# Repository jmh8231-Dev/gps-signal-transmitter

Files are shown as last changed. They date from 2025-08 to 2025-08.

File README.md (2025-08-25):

# GPS 데이터 송신기 (STM32F103 + ATmega328P)

두 개의 2.4 GHz RF 모듈(nRF24L01+ PA+LNA)과 GNSS, RTC, 환경 센서, 20×4 문자 LCD를 통합한 **원격 GPS 데이터 송신기**이다. 
보드는 **STM32F103C8T6**를 메인 MCU로, **ATmega328P**(Arduino 호환)를 서브 MCU로 사용한다. 서브 MCU는 센서 보조 처리 및
메인 MCU 상태 감시/리셋 보조를 담당한다. 펌웨어는 UBX 프로토콜로 GPS 시간을 수신하여 RTC(DS3231)를 보정하고,
RF/USB/UART로 상태를 송신한다.

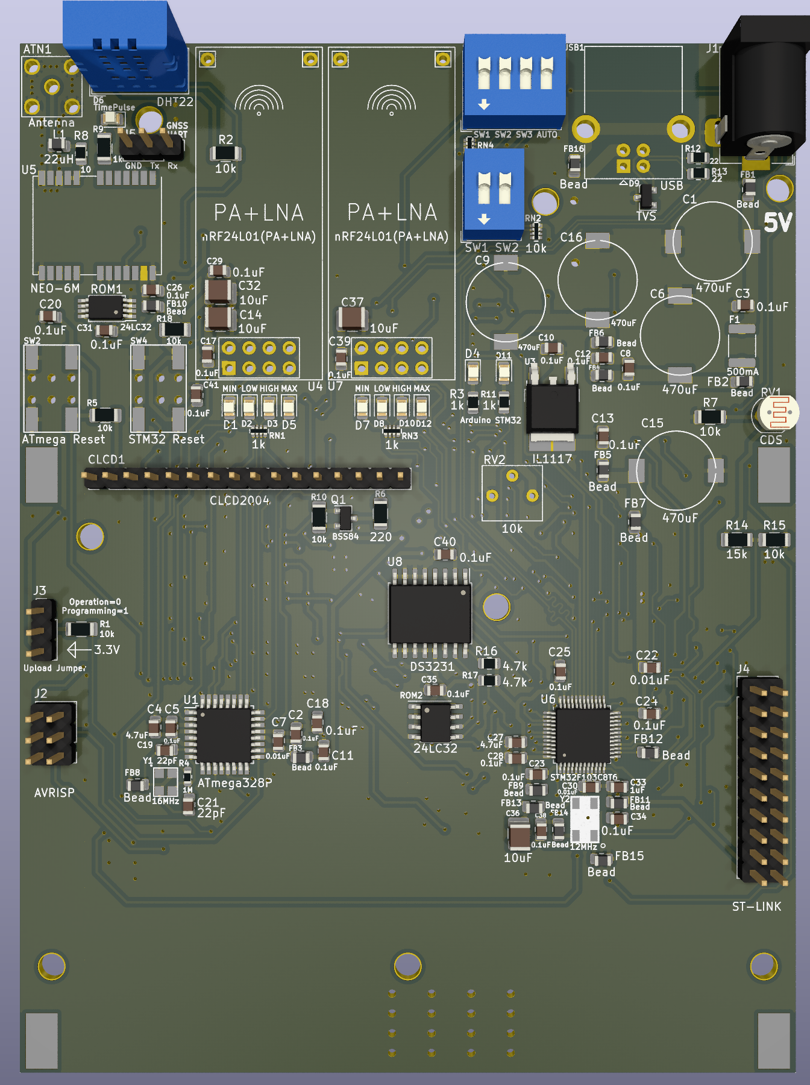
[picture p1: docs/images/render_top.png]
3D Render


---

## 1. 하드웨어 개요

- **MCU**
  - 메인: **STM32F103C8T6** (ST-LINK 20핀 헤더 제공)
  - 서브: **ATmega328P** (AVRISP 헤더, 16 MHz 크리스탈)
- **GNSS**
  - u‑blox **NEO-6M** 모듈(UBX 프로토콜), 백업 배터리(코인셀) 및 PPS/타임펄스 라우팅
- **무선(RF)**
  - **nRF24L01+ PA+LNA** 2개(각각 STM32/Arduino에 1개씩 연결), SMA 안테나
  - **DIP 스위치**로 송신 파워 레벨 설정(MIN/LOW/HIGH/MAX), **모두 OFF→MIN** 기본값
  - 파워 레벨 **LED 인디케이터** 제공
- **표시장치**
  - **20×4 캐릭터 LCD(CLCD2004)**, 백라이트 제어
- **센서**
  - **DHT22**(Temp/Hum) — 기본은 **ATmega328P**가 측정 → UART로 STM32에 전달
  - **CDS**(조도) — 야간에 LED OFF
- **시간/저장소**
  - **RTC: DS3231** (I²C), **EEPROM: 24LC32**
- **인터페이스/디버깅**
  - **USB‑to‑UART**(CDC 장치) 로그, **DFU**(USB) 업데이트
  - **ST‑LINK**, **AVRISP** 업로드 헤더, 수동/자동 리셋 회로

**참고 이미지**
- 스키매틱: `docs/images/schematic.png`
- PCB 레이아웃: `docs/images/pcb_layout.png`
- 동작 사진: `docs/images/photo_running.jpg`

---

## 2. 최종 동작 컨셉

1) **DIP 스위치로 RF 파워 레벨 제어**(STM32는 AUTO 모드 추가), **LED**로 단계 표시  
2) **USB‑to‑UART**로 디버깅/상태 표시(PC 미연결 시 LCD로 표시)  
3) **감시 구조**: STM32는 **IWDG**, ATmega328P는 **STM32에서 모니터링해 필요 시 리셋**  
4) **RTC 보정**: GPS 시간 수신 시 RTC 보정, GPS 부재 시 RTC 시간을 사용해 송신  
5) **2.4 GHz 간섭 방지**: **STM32 먼저 송신 → 신호 후 ATmega 송신**  
6) **DFU 업데이트**: SW 입력 조건에서 자동 리셋 + USB 활성화(펌웨어 업로드 편의성)

---

## 3. DIP 스위치/LED 정책

- **파워 레벨 매핑 (2비트 예시)**  
  `00 → MIN`, `01 → LOW`, `10 → HIGH`, `11 → MAX`  
  *모두 OFF일 경우 MIN로 동작.*
- **LED 표시**  
  레벨별 LED 켜짐(또는 LCD에 현재 단계 표시). 야간에는 **CDS** 감지로 LED OFF.

---

## 4. 펌웨어 구조

### 4.1 STM32 (핵심 루프)
- **GPS(UBX) 파싱** → **RTC(DS3231) 보정** → **LCD 표시(시각/출처/GPIO/전압·온도)** → **RF/USB 전송**
- **타이머(TIM2) 500 ms** 주기 이벤트로 LCD 갱신/주기 송신, **IWDG** 갱신
- **서브 MCU 감시**: UART로 수신된 헬스 바이트 점검, 이상 시 **ATmega328P 리셋 펄스**

주요 구현 포인트:
- UBX **NAV‑TIMEUTC** 메시지 파싱 및 체크섬 확인, GPS 유효 시각 판별(Valid bit)  
- GPS 유효 시 **RTC 보정**, 실패 시 **RTC 시각 사용**  
- LCD 4행 표시: 날짜·시간, 소스(GPS/RTC), 노드수(예약), 온습도(DHT22), VIN/MCU 온도  
- ATmega 리셋은 **최대 횟수 제한** 후 에러 플래그 표시

### 4.2 ATmega328P
- **DHT22 측정** → 결과 프레임을 **UART**로 STM32에 주기 전송  
- 특정 **PWM/헬스 신호 미수신** 시 STM32가 리셋(하드웨어 라인) 실행

---

## 5. 빌드/업로드

- **STM32**: STM32CubeIDE(HAL) 프로젝트. **ST‑LINK**로 프로그래밍. 필요 시 **DFU 모드** 진입 후 USB로 업데이트.
- **ATmega328P**: Arduino IDE 또는 AVR‑GCC. **AVRISP**(J2)로 업로드.
- 업로드 시 RF 모듈 탈착이 필요할 수 있으므로 점퍼를 통해 **Programming / Operation** 모드 선택.

---

## 6. 테스트 절차

1) USB 연결 후 CDC 시리얼 모니터로 로그 확인(보레이트 115200)  
2) GNSS 안테나 연결 → 위성 Lock 후 시간 동기화 확인  
3) DIP 스위치 단계 변경 → LED/LCD 표시 확인, RF 출력 단계 로깅  
4) DHT22 가열 시간 후 값 수신 → LCD 3행 온습도 표시 확인  
5) ISP 점퍼를 ‘Operation’으로 두고 재부팅 → 정상 동작 확인

---

## 7. 파일 트리

```text
gps-tx/
├─ README.md
├─ firmware/
│  ├─ stm32/        # main.c, GPS.c, GPS_Data_Repeater.c 등
│  └─ atmega/       # ATmega328P.ino
└─ docs/
   ├─ images/       # schematic.png, pcb_layout.png, render_top.png, photo_running.jpg
   └─ media/        # demo.mp4 (선택)
```

---

## 8. 이미지

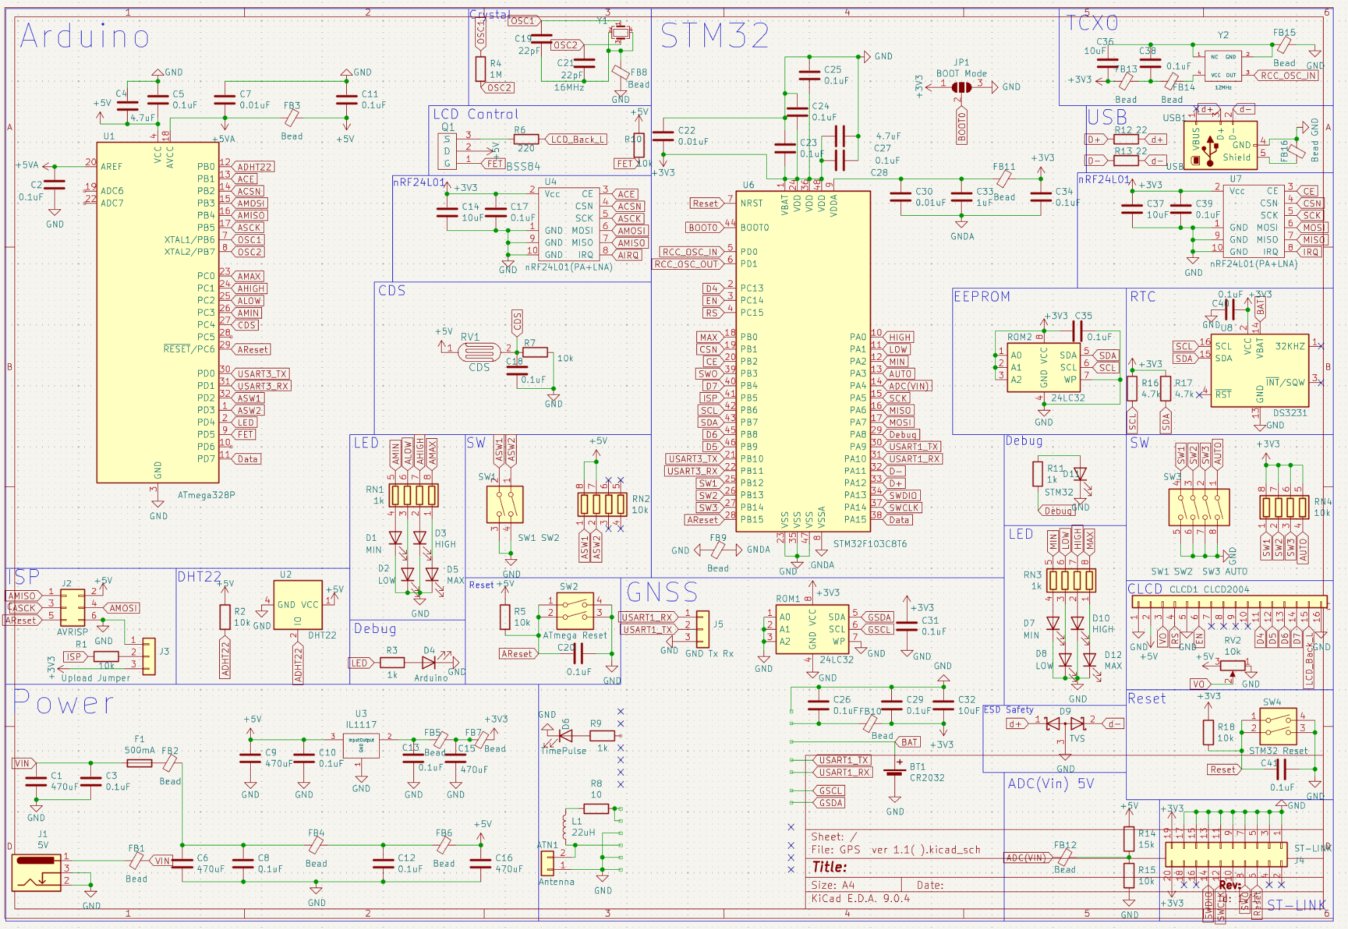
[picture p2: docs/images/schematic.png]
Schematic

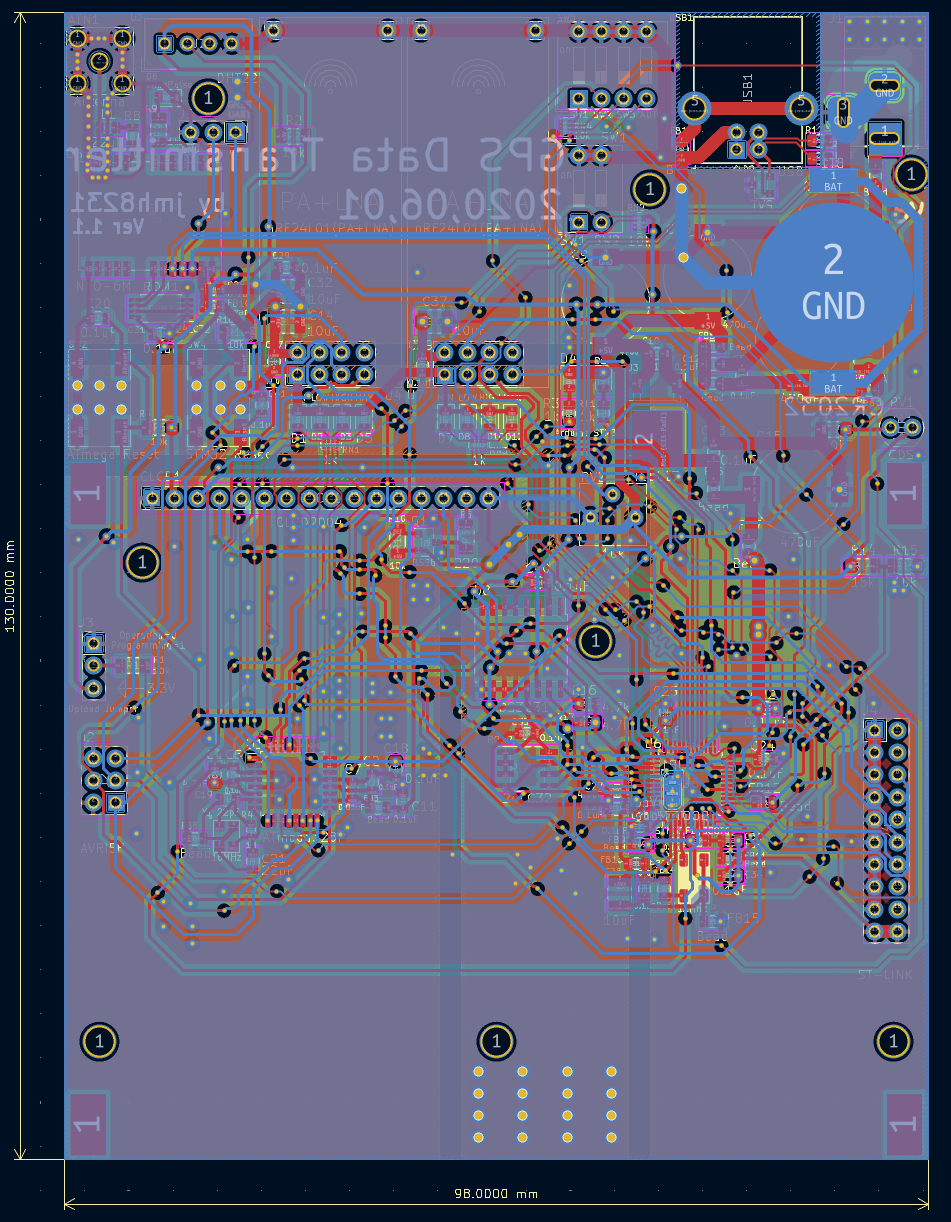
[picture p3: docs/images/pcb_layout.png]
Layout

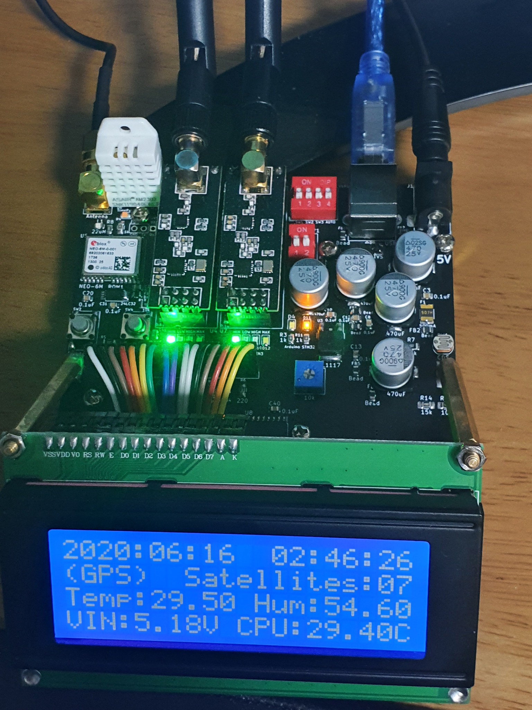
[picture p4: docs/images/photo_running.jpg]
Running


---

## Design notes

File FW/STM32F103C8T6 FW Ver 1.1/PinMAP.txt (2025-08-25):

//GPS 무선 송신 모듈 설계서(STM32F1C8T6) 개선버전

I2C1: 24LC32(EEPROM), DS3231(RTC)

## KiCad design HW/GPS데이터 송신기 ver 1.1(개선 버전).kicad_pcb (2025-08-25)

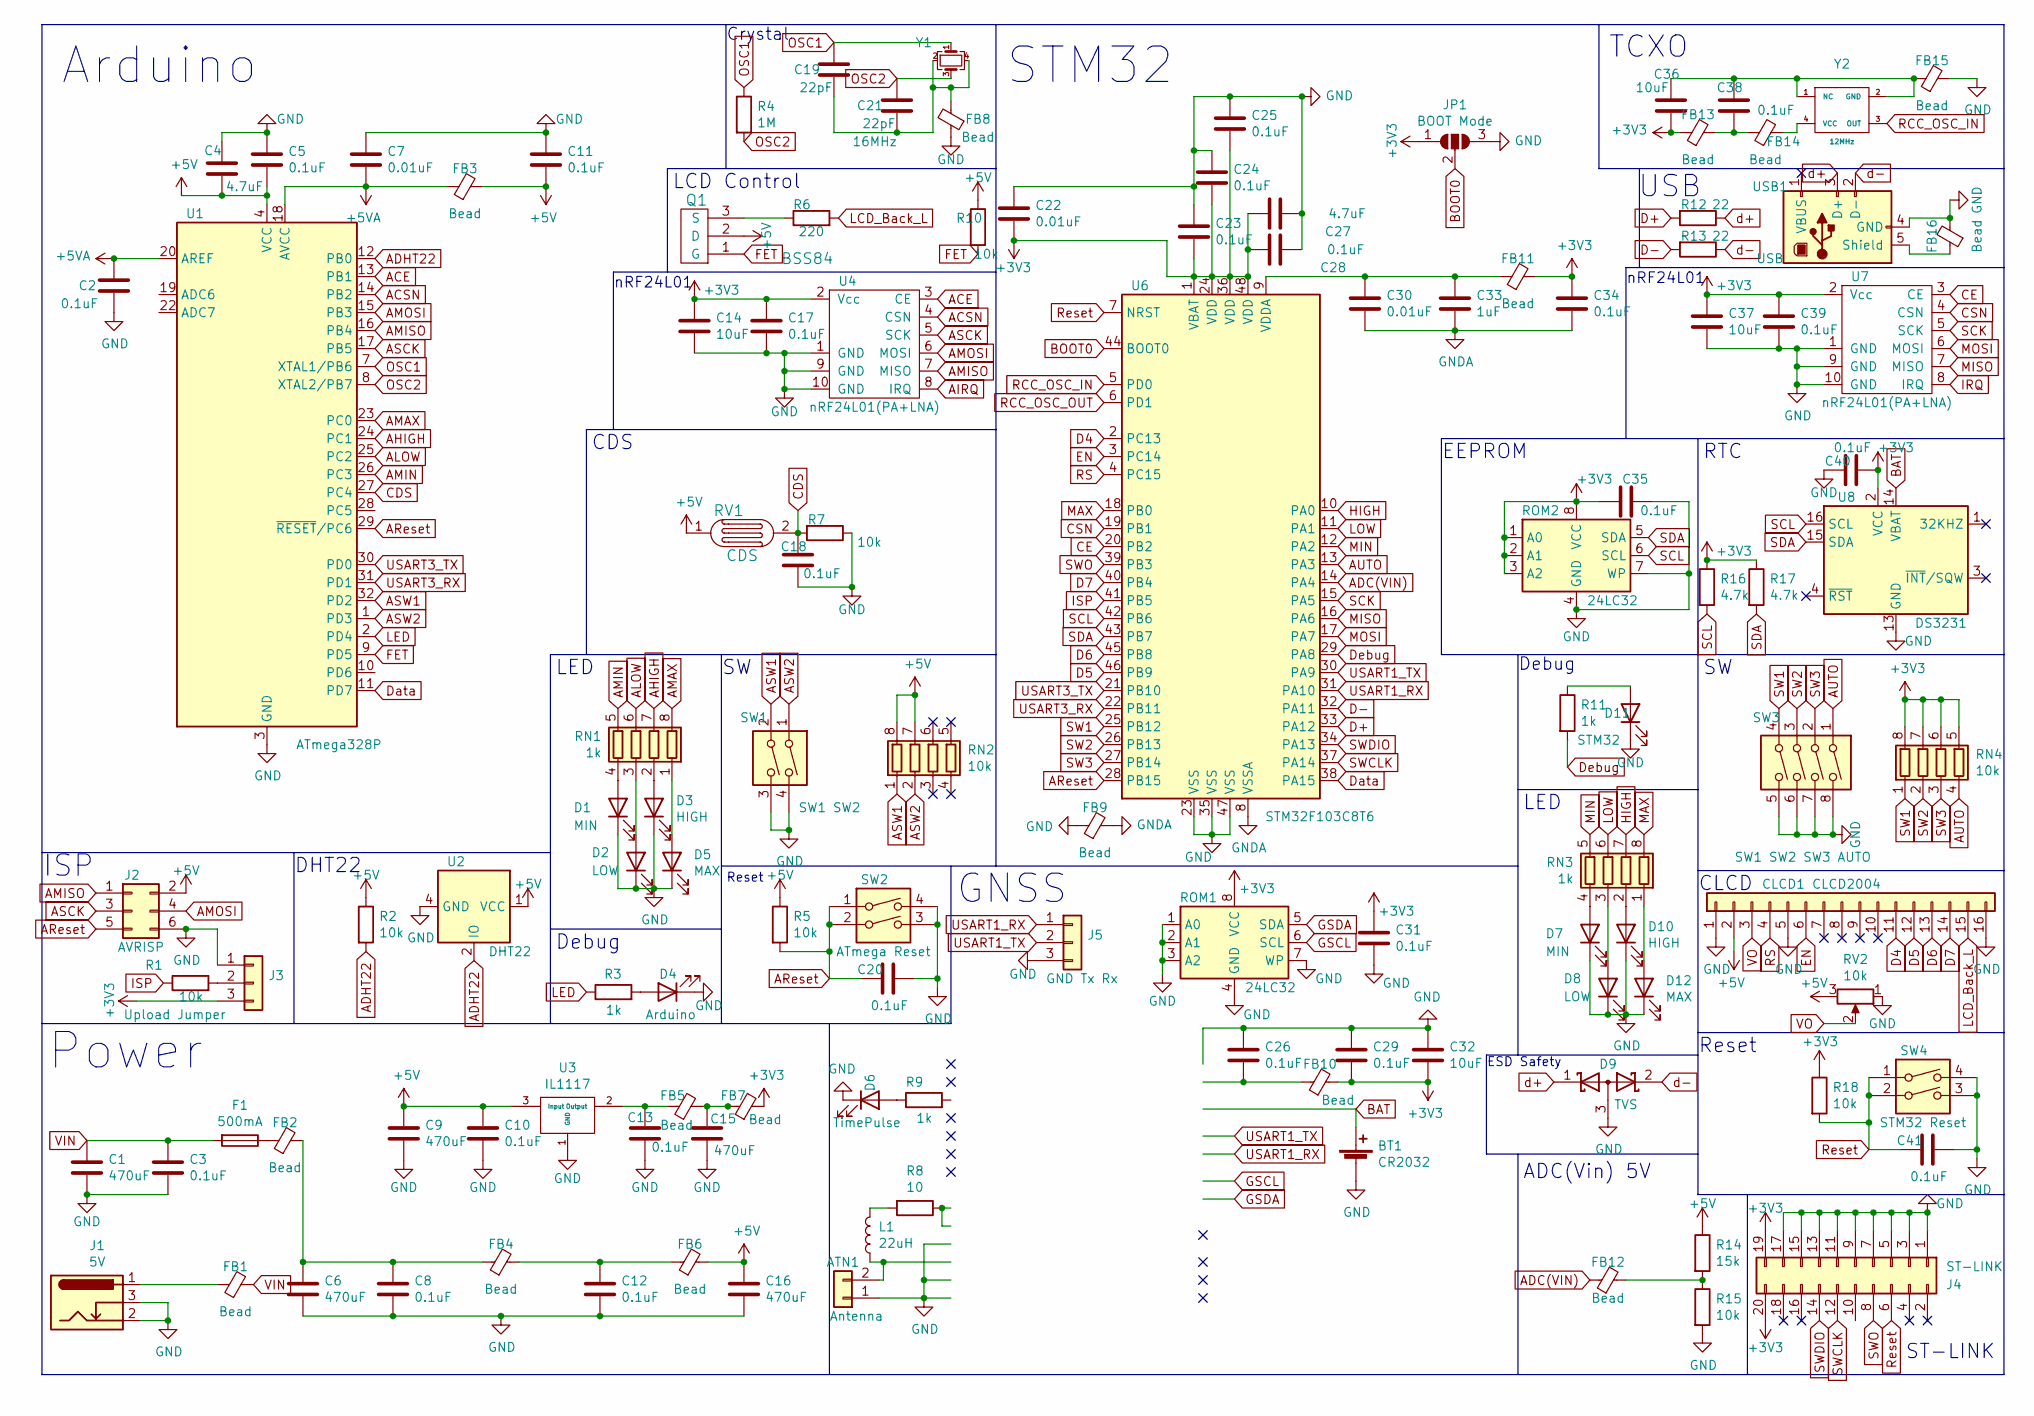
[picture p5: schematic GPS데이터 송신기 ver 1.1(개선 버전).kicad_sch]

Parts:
ATN1: Antenna; SMA
BT1: CR2032; BAT-HLD-001
C1, C6, C9, C15, C16: 470uF; MVG25WV470M
C2, C3, C5, C8, C10, C11, C12, C13, C17, C18, C20, C23, C24, C25, C26, C28, C29, C31, C34, C35, C38, C39, C40, C41: 0.1uF; C_0805_2012Metric
C4, C27: 4.7uF; C_0805_2012Metric
C7, C22, C30: 0.01uF; C_0805_2012Metric
C14, C32, C36, C37: 10uF; C_1210_3225Metric
C19, C21: 22pF; C_0805_2012Metric
C33: 1uF; C_0805_2012Metric
CLCD1: CLCD2004; PinHeader_1x16_P2.54mm_Vertical
D1, D7: MIN; LED_0805_2012Metric
D2, D8: LOW; LED_0805_2012Metric
D3, D10: HIGH; LED_0805_2012Metric
D4: Arduino; LED_0805_2012Metric
D5, D12: MAX; LED_0805_2012Metric
D6: TimePulse; LED_0805_2012Metric
D9: TVS; SOT-23
D11: STM32; LED_0805_2012Metric
F1: 500mA; Fuse_1812_4532Metric
FB1, FB2, FB3, FB4, FB5, FB6, FB7, FB8, FB9, FB10, FB11, FB12, FB13, FB14, FB15, FB16: Bead; L_0805_2012Metric
J1: 5V; BarrelJack_Horizontal
J2: AVRISP; PinHeader_2x03_P2.54mm_Vertical
J3: Upload Jumper; PinHeader_1x03_P2.54mm_Vertical
J4: ST-LINK; PinHeader_2x10_P2.54mm_Vertical
J5: GND Tx Rx; PinHeader_1x03_P2.54mm_Vertical
JP1: BOOT Mode; SolderJumper-3_P1.3mm_Open_RoundedPad1.0x1.5mm
L1: 22uH; L_0805_2012Metric
Q1: BSS84; SOT-23
R1, R2, R5, R7, R10, R15, R18: 10k; R_1206_3216Metric
R3, R11: 1k; R_0805_2012Metric
R4: 1M; R_0603_1608Metric
R6: 220; R_1206_3216Metric
R8: 10; R_0805_2012Metric
R9: 1k; R_1206_3216Metric
R12, R13: 22; R_0805_2012Metric
R14: 15k; R_1206_3216Metric
R16, R17: 4.7k; R_0805_2012Metric
RN1, RN3: 1k; R_Array_Convex_4x0402
RN2, RN4: 10k; R_Array_Convex_4x0402
ROM1: 24LC32; TSSOP-8_4.4x3mm_P0.65mm
ROM2: 24LC32; SOIC-8_3.9x4.9mm_P1.27mm
RV1: CDS; R_LDR_4.9x4.2mm_P2.54mm_Vertical
RV2: 10k; 3362P-103LF
SW1: SW1 SW2; SW_DIP_SPSTx02_Slide_9.78x7.26mm_W7.62mm_P2.54mm
SW2: ATmega Reset; SW_SMD_IT-1107
SW3: SW1 SW2 SW3 AUTO; SW_DIP_SPSTx04_Slide_9.78x12.34mm_W7.62mm_P2.54mm
SW4: STM32 Reset; SW_SMD_IT-1107
U1: ATmega328P; TQFP-32_7x7mm_P0.8mm
U2: DHT22; Aosong_DHT11_5.5x12.0_P2.54mm
U3: IL1117; TO-252-2
U4, U7: nRF24L01(PA+LNA)
U6: STM32F103C8T6; LQFP-48_7x7mm_P0.5mm
U8: DS3231; SOIC-16W_7.5x10.3mm_P1.27mm
USB1: USB; USB_B_OST_USB-B1HSxx_Horizontal
Y1: 16MHz; TSX-3225 16.0000MF18X-AC0
Y2: 12MHz; FT5HNBPK12.0-T1

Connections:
+3V3: C14.1, C17.1, C22.2, C23.1, C24.1, C25.1, C27.1, C28.2, C29.2, C31.1, C32.2, C34.1, C35.2, C36.2, C37.1, C39.1, C40.1, FB7.2, FB10.2, FB11.2, FB13.1, J3.3, J4.19, J4.20, JP1.1 (A), R16.1, R17.1, R18.1, RN4.5 (R4.2), RN4.6 (R3.2), RN4.7 (R2.2), RN4.8 (R1.2), ROM1.8 (VCC), ROM2.1 (A0), ROM2.2 (A1), ROM2.3 (A2), ROM2.8 (VCC), U4.2 (Vcc), U6.1 (VBAT), U6.24 (VDD), U6.36 (VDD), U6.48 (VDD), U7.2 (Vcc), U8.2 (VCC)
+5V: C4.1, C5.1, C9.1, C10.1, C11.2, C16.1, CLCD1.2, FB3.2, FB6.2, J2.2, Q1.2 (D), R2.1, R5.1, R10.1, R14.1, RN2.7 (R2.2), RN2.8 (R1.2), RV1.1, RV2.3, U1.4 (VCC), U1.6 (VCC), U2.1 (VCC), U3.3 (Input)
+5VA: C2.2, C7.2, FB3.1, U1.18 (AVCC), U1.20 (AREF)
ACE: U1.13 (PB1), U4.3 (CE)
ACSN: U1.14 (PB2), U4.4 (CSN)
ADC(VIN): FB12.1, U6.14 (PA4)
ADHT22: R2.2, U1.12 (PB0), U2.2 (IO)
AHIGH: RN1.7 (R2.2), U1.24 (PC1)
AIRQ: U4.8 (IRQ)
ALOW: RN1.6 (R3.2), U1.25 (PC2)
AMAX: RN1.8 (R1.2), U1.23 (PC0)
AMIN: RN1.5 (R4.2), U1.26 (PC3)
AMISO: J2.1, U1.16 (PB4), U4.7 (MISO)
AMOSI: J2.4, U1.15 (PB3), U4.6 (MOSI)
AReset: C20.2, J2.5, R5.2, SW2.1, SW2.2, U1.29 (~RESET/PC6), U6.28 (PB15)
ASCK: J2.3, U1.17 (PB5), U4.5 (SCK)
ASW1: RN2.1 (R1.1), SW1.2, U1.32 (PD2)
ASW2: RN2.2 (R2.1), SW1.1, U1.1 (PD3)
AUTO: RN4.4 (R4.1), SW3.1, U6.13 (PA3)
BAT: BT1.1 (+), U8.14 (VBAT); also elsewhere on the board
BOOT0: JP1.2 (C), U6.44 (BOOT0)
CDS: C18.1, R7.2, RV1.2, U1.27 (PC4)
CE: U6.20 (PB2), U7.3 (CE)
CSN: U6.19 (PB1), U7.4 (CSN)
D4: CLCD1.11, U6.2 (PC13)
D5: CLCD1.12, U6.46 (PB9)
D6: CLCD1.13, U6.45 (PB8)
D7: CLCD1.14, U6.40 (PB4)
D+: R12.2, U6.33 (PA12)
D-: R13.2, U6.32 (PA11)
Data: U1.11 (PD7), U6.38 (PA15)
Debug: R11.2, U6.29 (PA8)
EN: CLCD1.6, U6.3 (PC14)
FET: Q1.1 (G), R10.2, U1.9 (PD5)
GND: ATN1.1, BT1.2 (-), C1.2, C2.1, C3.2, C4.2, C5.2, C6.2, C7.1, C8.2, C9.2, C10.2, C11.1, C12.2, C13.2, C14.2, C15.2, C16.2, C17.2, C18.2, C20.1, C22.1, C23.2, C24.2, C25.2, C26.1, C27.2, C28.1, C29.1, C31.2, C32.1, C35.1, C37.2, C39.2, C40.2, C41.1, CLCD1.1, CLCD1.5, CLCD1.16, D1.1 (K), D2.1 (K), D3.1 (K), D4.1 (K), D5.1 (K), D6.1 (K), D7.1 (K), D8.1 (K), D9.3 (A), D10.1 (K), D11.1 (K), D12.1 (K), FB8.1, FB9.1, FB15.2, FB16.2, J1.2, J1.3, J2.6, J3.1, J4.1, J4.3, J4.5, J4.7, J4.9, J4.11, J4.13, J4.15, J4.17, J5.3, JP1.3 (B), R7.1, R15.2, ROM1.1 (A0), ROM1.2 (A1), ROM1.3 (A2), ROM1.4 (GND), ROM1.7 (WP), ROM2.4 (GND), ROM2.7 (WP), RV2.1, SW1.3, SW1.4, SW2.3, SW2.4, SW3.5, SW3.6, SW3.7, SW3.8, SW4.3, SW4.4, U1.3 (GND), U1.5 (GND), U1.21 (GND), U2.4 (GND), U3.1 (GND), U4.1 (GND), U4.9 (GND), U4.10 (GND), U6.23 (VSS), U6.35 (VSS), U6.47 (VSS), U7.1 (GND), U7.9 (GND), U7.10 (GND), U8.5 (GND), U8.6 (GND), U8.7 (GND), U8.8 (GND), U8.9 (GND), U8.10 (GND), U8.11 (GND), U8.12 (GND), U8.13 (GND), USB1.4 (GND); also elsewhere on the board
GNDA: C30.2, C33.2, C34.2, FB9.2, U6.8 (VSSA)
GSCL: ROM1.6 (SCL); also elsewhere on the board
GSDA: ROM1.5 (SDA); also elsewhere on the board
HIGH: RN3.7 (R2.2), U6.10 (PA0)
IRQ: U7.8 (IRQ)
ISP: R1.1, U6.41 (PB5)
LCD_Back_L: CLCD1.15, R6.2
LED: R3.1, U1.2 (PD4)
LOW: RN3.6 (R3.2), U6.11 (PA1)
MAX: RN3.8 (R1.2), U6.18 (PB0)
MIN: RN3.5 (R4.2), U6.12 (PA2)
MISO: U6.16 (PA6), U7.7 (MISO)
MOSI: U6.17 (PA7), U7.6 (MOSI)
unnamed 48: ATN1.2, L1.1; also elsewhere on the board
unnamed: C6.1, C8.1, FB2.2, FB4.1
unnamed: C12.1, FB4.2, FB6.1
unnamed: C13.1, FB5.1, U3.2 (Output)
unnamed: C15.1, FB5.2, FB7.1
unnamed: C19.2, C21.1, FB8.2, Y1.2, Y1.4
unnamed 54: C26.2, FB10.1; also elsewhere on the board
unnamed: C30.1, C33.1, FB11.1, U6.9 (VDDA)
unnamed: C36.1, C38.1, FB15.1, Y2.1 (NC), Y2.2 (GND)
unnamed: C38.2, FB13.2, FB14.1
unnamed: D1.2 (A), RN1.4 (R4.1)
unnamed: D2.2 (A), RN1.3 (R3.1)
unnamed: D3.2 (A), RN1.2 (R2.1)
unnamed: D4.2 (A), R3.2
unnamed: D5.2 (A), RN1.1 (R1.1)
unnamed: D6.2 (A), R9.1
unnamed: D7.2 (A), RN3.4 (R4.1)
unnamed: D8.2 (A), RN3.3 (R3.1)
unnamed: D10.2 (A), RN3.2 (R2.1)
unnamed: D11.2 (A), R11.1
unnamed: D12.2 (A), RN3.1 (R1.1)
unnamed: F1.1, FB2.1
unnamed: FB1.1, J1.1
unnamed: FB12.2, R14.2, R15.1
unnamed: FB14.2, Y2.4 (VCC)
unnamed: FB16.1, USB1.5 (Shield)
unnamed: J3.2, R1.2
unnamed: L1.2, R8.2
unnamed: Q1.3 (S), R6.1
unnamed 86: R8.1; also elsewhere on the board
unnamed 87: R9.2; also elsewhere on the board
OSC1: C19.1, R4.1, U1.7 (XTAL1/PB6), Y1.1
OSC2: C21.2, R4.2, U1.8 (XTAL2/PB7), Y1.3
RCC_OSC_IN: U6.5 (PD0), Y2.3 (OUT)
RCC_OSC_OUT: U6.6 (PD1)
RS: CLCD1.4, U6.4 (PC15)
Reset: C41.2, J4.6, R18.2, SW4.1, SW4.2, U6.7 (NRST)
SCK: U6.15 (PA5), U7.5 (SCK)
SCL: R16.2, ROM2.6 (SCL), U6.42 (PB6), U8.16 (SCL)
SDA: R17.2, ROM2.5 (SDA), U6.43 (PB7), U8.15 (SDA)
SW1: RN4.1 (R1.1), SW3.4, U6.25 (PB12)
SW2: RN4.2 (R2.1), SW3.3, U6.26 (PB13)
SW3: RN4.3 (R3.1), SW3.2, U6.27 (PB14)
SWCLK: J4.12, U6.37 (PA14)
SWDIO: J4.14, U6.34 (PA13)
SWO: J4.8, U6.39 (PB3)
USART1_RX: J5.1, U6.31 (PA10); also elsewhere on the board
USART1_TX: J5.2, U6.30 (PA9); also elsewhere on the board
USART3_RX: U1.31 (PD1), U6.22 (PB11)
USART3_TX: U1.30 (PD0), U6.21 (PB10)
VIN: C1.1, C3.1, F1.2, FB1.2
VO: CLCD1.3, RV2.2
d+: D9.1 (K), R12.1, USB1.3 (D+)
d-: D9.2 (K), R13.1, USB1.2 (D-)

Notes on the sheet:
DHT22
STM32
LED
Debug
ISP
Power
Debug
Arduino
ADC(Vin) 5V
ST-LINK
CDS
TCXO
Reset
ESD Safety
RTC
LCD Control
nRF24L01
CLCD
Crystal
EEPROM
GNSS
USB

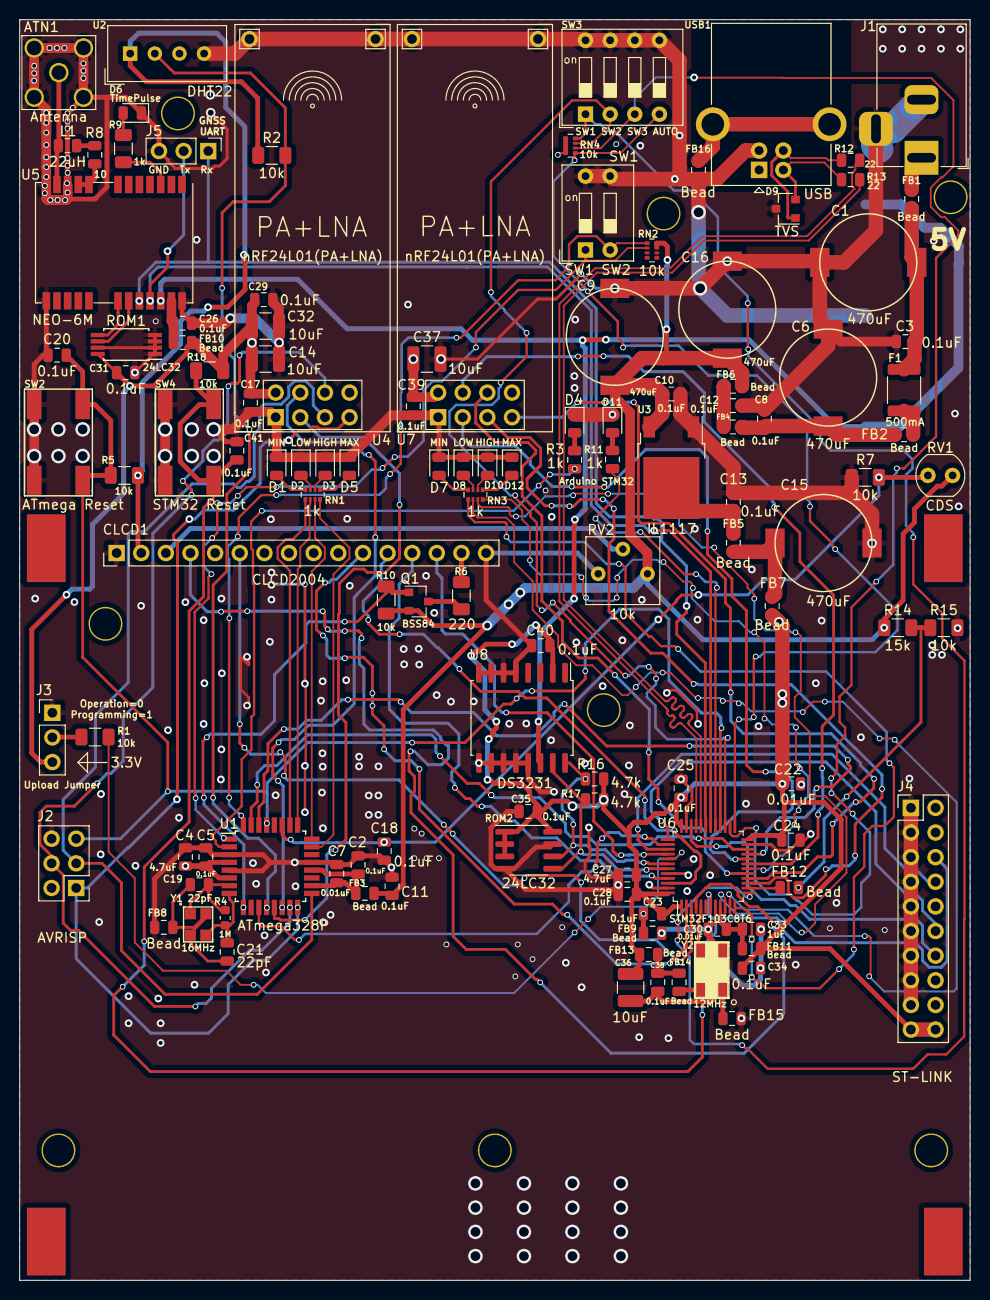
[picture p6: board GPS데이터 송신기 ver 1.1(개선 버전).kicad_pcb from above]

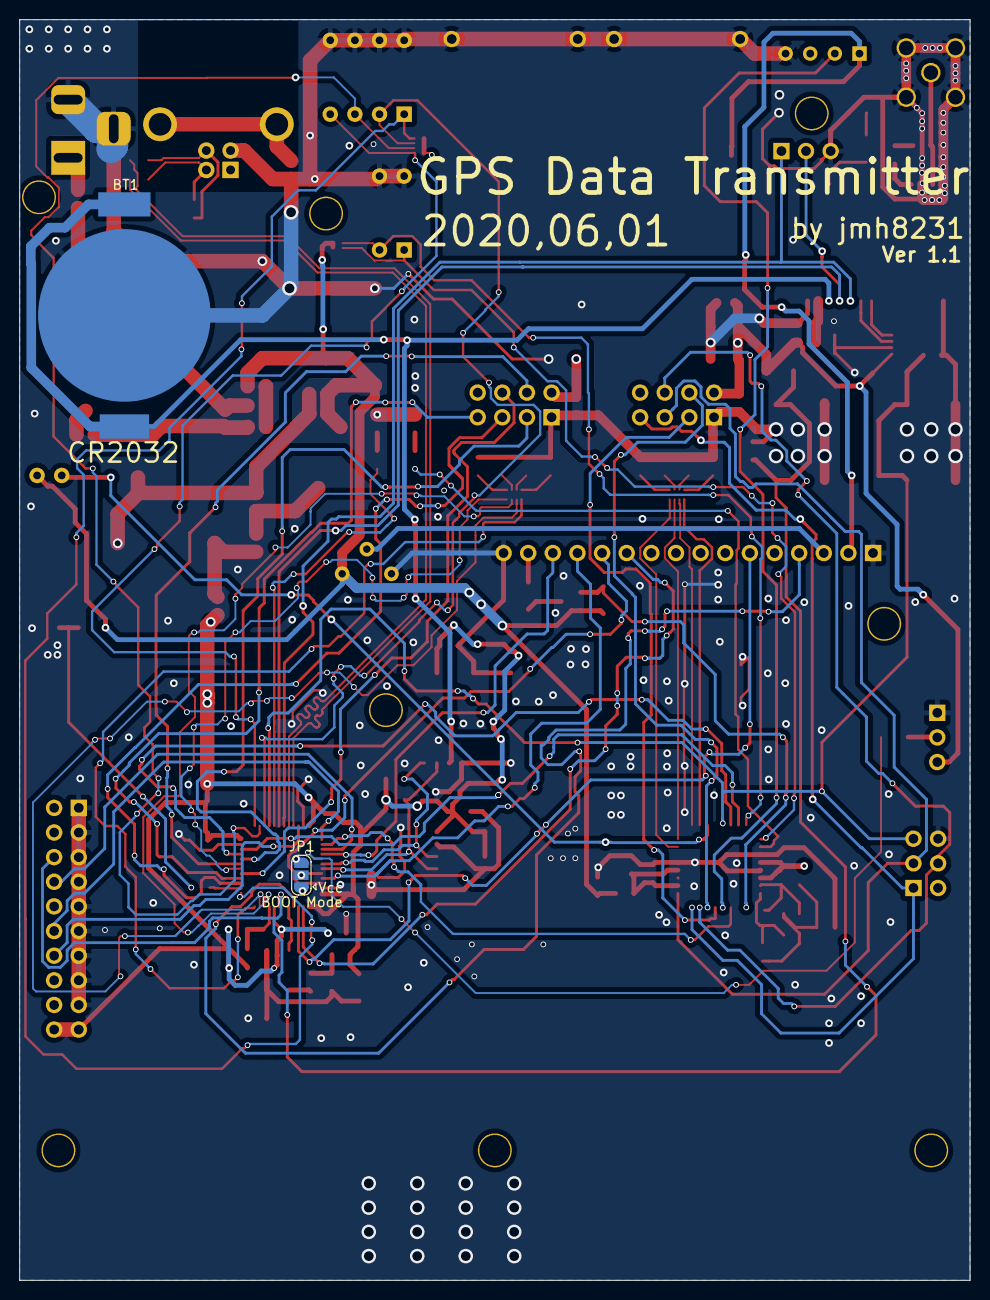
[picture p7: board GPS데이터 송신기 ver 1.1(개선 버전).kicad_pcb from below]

Board: 4 copper layers, 98.0 x 130.0 mm, 134 parts (2 on the bottom side), 99 nets.

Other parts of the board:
 : Pad
 #2,  #8,  #9: Pad
 #3,  #4,  #5,  #6,  #7,  #10,  #11,  #12: h
U5: NEO-6M; ublox_NEO

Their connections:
BAT: U5.22; also elsewhere on the board
GND: U5.10, U5.12, U5.13, U5.24; also elsewhere on the board
GSCL: U5.19; also elsewhere on the board
GSDA: U5.18; also elsewhere on the board
unnamed 48: U5.11; also elsewhere on the board
unnamed 54: U5.23; also elsewhere on the board
unnamed 86: U5.8, U5.9; also elsewhere on the board
unnamed 87: U5.3; also elsewhere on the board
USART1_RX: U5.20; also elsewhere on the board
USART1_TX: U5.21; also elsewhere on the board

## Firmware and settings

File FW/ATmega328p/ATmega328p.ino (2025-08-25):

//GPS데이터 송신기

//21.12.12 업데이트 내용: 주변 밝기에 따라 LED 제어 구현

//DHT22를 위한 라이브러리
#include "DHT.h"

//RF모듈을 위한 라이브러리
#include <SPI.h>
#include "RF24.h"

//타이머 인터럽트
#include <MsTimer2.h>

//통신 모듈 설정
RF24 radio(9, 10);//9번핀을 CE, 10번핀을 CSN으로 SPI통신 설정
const byte addresses[6] = "132435";//파이프 주소를 설정

//온습도 센서 설정
DHT DHT(8, DHT22);

//시간 저장 변수
byte TimeData[6];

//RF모듈로 전송할 시간 데이터
char RFTimeData[32];

//주변 밝기를 전송할 변수(STM32)
char LEDflag = 'B';

//주변 밝기를 저장할 변수(아두이노)
bool ledflag = 0;

//STM32로 전송할 데이터
String Data;

//온습도 데이터
//STM32 DMA특성 때문에 더미 데이터 저장
float Hum = 12.34; 
float Temp = 56.78;

int Sean_flag = 0;

void setup() 
{
  //STM32와 UART통신 초기화
  Serial.begin(115200);
  
  //무선통신 모듈 설정
  radio.begin();//무선 통신 모듈 초기화
  radio.setPALevel(RF24_PA_MIN);//거리가 가까운 순으로 RF24_PA_MIN / RF24_PA_LOW / RF24_PA_HIGH / RF24_PA_MAX
  radio.openWritingPipe(addresses);//데이터를 보낼 주소 설정
  radio.stopListening();//송신 모드로 설정

  //센서 초기화
  DHT.begin();
  
  //타이머 인터럽트 설정
  MsTimer2::set(2500, Toggle);// 2500ms 단위로 Toggle() 함수 호출
  MsTimer2::start();//인터럽트 실행
}

//IO핀 레지스터 설정
void PinModeSetUP()
{
  pinMode(2, INPUT);//SW1
  pinMode(3, INPUT);//SW2
  pinMode(4, OUTPUT);//Debug LED
  pinMode(5, OUTPUT);//FET
  pinMode(7, INPUT);//RF모듈 송신 타이밍용
  pinMode(14, OUTPUT);//MIN LED
  pinMode(15, OUTPUT);//LOW LED
  pinMode(16, OUTPUT);//HIGH LED
  pinMode(17, OUTPUT);//MAX LED
}

void TransmitData(char TxData[32])
{
  //MIN모드
  if(digitalRead(2) == LOW && digitalRead(3) == LOW)
  {
    radio.setPALevel(RF24_PA_MIN);

    if(ledflag == 1)
    {
      digitalWrite(14, HIGH);
      digitalWrite(15, LOW);
      digitalWrite(16, LOW);
      digitalWrite(17, LOW);
    }
    else
    {
      digitalWrite(14, LOW);
      digitalWrite(15, LOW);
      digitalWrite(16, LOW);
      digitalWrite(17, LOW);
    }

    radio.write(&TxData, sizeof(TxData));//시간 데이터를 전송 
  }
  
  //LOW모드
  else if(digitalRead(2) == HIGH && digitalRead(3) == LOW)
  {
    radio.setPALevel(RF24_PA_LOW);

    if(ledflag == 1)
    {
      digitalWrite(14, LOW);
      digitalWrite(15, HIGH);
      digitalWrite(16, LOW);
      digitalWrite(17, LOW);
    }
    else
    {
      digitalWrite(14, LOW);
      digitalWrite(15, LOW);
      digitalWrite(16, LOW);
      digitalWrite(17, LOW);
    }

    radio.write(&TxData, sizeof(TxData));//시간 데이터를 전송 
  }

  //HIGH모드
  else if(digitalRead(2) == LOW && digitalRead(3) == HIGH)
  {
    radio.setPALevel(RF24_PA_HIGH);

    if(ledflag == 1)
    {
      digitalWrite(14, LOW);
      digitalWrite(15, LOW);
      digitalWrite(16, HIGH);
      digitalWrite(17, LOW);
    }
    else
    {
      digitalWrite(14, LOW);
      digitalWrite(15, LOW);
      digitalWrite(16, LOW);
      digitalWrite(17, LOW);
    }

    radio.write(&TxData, sizeof(TxData));//시간 데이터를 전송 
  }

  //MAX모드
  else if(digitalRead(2) == HIGH && digitalRead(3) == HIGH)
  {
    radio.setPALevel(RF24_PA_MAX);

    if(ledflag == 1)
    {
      digitalWrite(14, LOW);
      digitalWrite(15, LOW);
      digitalWrite(16, LOW);
      digitalWrite(17, HIGH);
    }
    else
    {
      digitalWrite(14, LOW);
      digitalWrite(15, LOW);
      digitalWrite(16, LOW);
      digitalWrite(17, LOW);
    }

    radio.write(&TxData, sizeof(TxData));//시간 데이터를 전송 
  }
}

//LCD백라이트 컨트롤 함수
void FET_Control()
{          
  //CDS셀 데이터
  int Brightness;

  Brightness = analogRead(A4);

  if(Brightness > 100)
  {
    digitalWrite(5, LOW);
    LEDflag = 'B';
    ledflag = 1;
  }
  else
  {
    digitalWrite(5, HIGH);
    LEDflag = 'C';
    ledflag = 0;
  }
}

void CheckFlag()
{
  if(Sean_flag == 1)
  {
    Sean_flag = 0;

    //습도값을 변수에 저장
    Hum = DHT.readHumidity();
    //온도값을 변수에 저장
    Temp = DHT.readTemperature();
  }
}

void loop()
{
  //리셋을 방지하기 위해 WDT 전송
  Data = String(Hum) + String(Temp) + 'A' + String(LEDflag); 
  Serial.print(Data);
  
  //핀 모드를 정해주는 함수(오류로인해 핀 모드 레지스터가 바뀌어도 바로 수정할수 있다)
  PinModeSetUP(); 
  
  //만약 시간 데이터를 수신하면
  if(Serial.available() > 0)
  {
    //시간데이터를 읽어와 배열에 저장
    for(int i = 0; i < 6; i++)
    {
      TimeData[i] = Serial.read();//시간 데이터 저장
    }
  }
  
  //만약 STM32가 전송을 끝냈으면
  if(digitalRead(7) == LOW)
  {
    //바이트형 배열을 문자열로 변환
    String Time = String(TimeData[0]) + "/" + String(TimeData[1]) + "/" + String(TimeData[2]) + "/" + String(TimeData[3]) + "/" + String(TimeData[4]) + "/" + String(TimeData[5]);

    //문자열을 char형 배열로 변환
    Time.toCharArray(RFTimeData, Time.length() + 1);//수신기로 전송하기 위해 char형 변수로 바꾸어 저장
    
    TransmitData(RFTimeData);//시간정보 전송
  }
  
  //밝기를 센싱하여 LCD백라이트 제어   
  FET_Control();

  CheckFlag();//flag변수들을 확인하는 함수
}

void Toggle()//3초마다 실행되는 함수
{
  if(ledflag == 1)
  {
    //Debug LED 토글
    static boolean output = HIGH;
    digitalWrite(4, output);
    output =! output;
  }
  else
  {
    digitalWrite(4, LOW);
  }
  
    Sean_flag = 1;
}

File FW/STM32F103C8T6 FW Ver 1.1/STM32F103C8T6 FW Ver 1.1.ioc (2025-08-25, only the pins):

Mcu.UserName=STM32F103C8Tx
PA0-WKUP.GPIO_Label=LD_HIGH
PA0-WKUP.Signal=GPIO_Output
PA1.GPIO_Label=LD_LOW
PA1.Signal=GPIO_Output
PA10.GPIO_Label=GPS_Rx
PA10.Signal=USART1_RX
PA11.Signal=USB_DM
PA12.Signal=USB_DP
PA13.Signal=SYS_JTMS-SWDIO
PA14.Signal=SYS_JTCK-SWCLK
PA15.GPIO_Label=Status
PA15.Signal=GPIO_Output
PA2.GPIO_Label=LD_MIN
PA2.Signal=GPIO_Output
PA3.GPIO_Label=SW_4
PA3.Signal=GPIO_Input
PA4.GPIO_Label=ADC_VIN
PA4.Signal=ADCx_IN4
PA5.Signal=SPI1_SCK
PA6.Signal=SPI1_MISO
PA7.Signal=SPI1_MOSI
PA8.GPIO_Label=LD_Debug
PA8.Signal=GPIO_Output
PA9.GPIO_Label=GPS_Tx
PA9.Signal=USART1_TX
PB0.GPIO_Label=LD_MAX
PB0.Signal=GPIO_Output
PB1.GPIO_Label=SPI1_CS
PB1.Signal=GPIO_Output
PB10.GPIO_Label=ATmega328p_Tx
PB10.Signal=USART3_TX
PB11.GPIO_Label=ATmega328p_Rx
PB11.Signal=USART3_RX
PB12.GPIO_Label=SW_1
PB12.Signal=GPIO_Input
PB13.GPIO_Label=SW_2
PB13.Signal=GPIO_Input
PB14.GPIO_Label=SW_3
PB14.Signal=GPIO_Input
PB15.GPIO_Label=ATmega328p_Reset
PB15.Signal=GPIO_Output
PB2.GPIO_Label=SPI1_CE
PB2.Signal=GPIO_Output
PB3.GPIO_Label=USB_EN
PB3.Signal=GPIO_Output
PB4.GPIO_Label=D7
PB4.Signal=GPIO_Output
PB5.GPIO_Label=ISP
PB5.Signal=GPIO_Input
PB6.Signal=I2C1_SCL
PB7.Signal=I2C1_SDA
PB8.GPIO_Label=D6
PB8.Signal=GPIO_Output
PB9.GPIO_Label=D5
PB9.Signal=GPIO_Output
PC13-TAMPER-RTC.GPIO_Label=D4
PC13-TAMPER-RTC.Signal=GPIO_Output
PC14-OSC32_IN.GPIO_Label=EN
PC14-OSC32_IN.Signal=GPIO_Output
PC15-OSC32_OUT.GPIO_Label=RS
PC15-OSC32_OUT.Signal=GPIO_Output
PD0-OSC_IN.Signal=RCC_OSC_IN
PD1-OSC_OUT.Signal=RCC_OSC_OUT

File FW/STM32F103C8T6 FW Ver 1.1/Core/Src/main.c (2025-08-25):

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
/* Includes ------------------------------------------------------------------*/
#include "main.h"
#include "adc.h"
#include "dma.h"
#include "i2c.h"
#include "iwdg.h"
#include "spi.h"
#include "tim.h"
#include "usart.h"
#include "usb_device.h"
#include "gpio.h"

/* USER CODE BEGIN Includes */
#include "CLCD.h"
#include "GPS.h"
#include "DS3231.h"
#include "GPS_Data_Repeater.h"

/* USER CODE END Includes */

/* USER CODE BEGIN PM */
int _write(int file, char *ptr, int len){
	HAL_GPIO_WritePin(USB_EN_GPIO_Port, USB_EN_Pin, GPIO_PIN_SET);
    CDC_Transmit_FS(ptr, len);
    return (len);
}

/* USER CODE END PM */


/* USER CODE BEGIN PV */

uint8_t rx_uart1_data;
extern uint8_t m6n_rx_buf[TIMEUTC_LEN];
extern uint8_t m6n_rx_cplt_flag;

extern uint8_t rx_uart3_Data[20] = {0, };

bool TIM2_flag = false;

/* USER CODE END PV */

void SystemClock_Config(void);
static void MX_NVIC_Init(void);
/**
  * @brief  The application entry point.
  * @retval int
  */
int main(void)
{

  /* MCU Configuration--------------------------------------------------------*/

  /* Reset of all peripherals, Initializes the Flash interface and the Systick. */
  HAL_Init();

  /* Configure the system clock */
  SystemClock_Config();

  /* Initialize all configured peripherals */
  MX_GPIO_Init();
  MX_DMA_Init();
  MX_I2C1_Init();
  MX_ADC1_Init();
  MX_SPI1_Init();
  MX_USART1_UART_Init();
  MX_USART3_UART_Init();
  MX_USB_DEVICE_Init();
  MX_TIM2_Init();
  MX_TIM1_Init();
  MX_IWDG_Init();

  /* Initialize interrupts */
  MX_NVIC_Init();
  /* USER CODE BEGIN 2 */

  //LCD 초기화
  HAL_TIM_Base_Start(&htim1);
  lcd_Init(20, 4);

  //GPS Module 초기화
  M6N_Init();
  HAL_UART_Receive_IT(&huart1, &rx_uart1_data, 1);

  //RTC 초기화
  DS3231_Init(&hi2c1);

  //ATmega328p 초기화
  ATmega328p_Reset();
  HAL_UART_Receive_DMA(&huart3, rx_uart3_Data, 12);

  //500ms TIM 인터럽트 시작
  HAL_TIM_Base_Start_IT(&htim2);

  //ADC변환 시작
  uint16_t ADCVAL[2] = {0, };
  HAL_ADC_Start_DMA(&hadc1, &ADCVAL[0], 2);

  //모든 장치 초기화를 마치고 WDT가동
  HAL_IWDG_Init(&hiwdg);

  bool led_flag;

  _RTC rtc;
  TIME time;
  /* USER CODE END 2 */

  /* Infinite loop */
  /* USER CODE BEGIN WHILE */
  while (1)
  {
	  HAL_IWDG_Refresh(&hiwdg);
	  Time_Calibration(&time, m6n_rx_buf, &rtc);
	  if(TIM2_flag)
	  {
		  send_Data(&time);
		  TIM2_flag = false;
		  Display(&time, &ADCVAL);
		  led_flag = SubMCU_Check();
	  }
    /* USER CODE END WHILE */

    /* USER CODE BEGIN 3 */
  }
  /* USER CODE END 3 */
}

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
/* USER CODE BEGIN 4 */
void HAL_UART_RxCpltCallback(UART_HandleTypeDef *huart)
{
	static unsigned char cnt = false;
	if(huart->Instance == USART1)
	{
		switch(cnt)
		{
		case 0:
			if(rx_uart1_data == 0xb5)
			{
				m6n_rx_buf[cnt] = rx_uart1_data;
				cnt++;
			}
			break;
		case 1:
			if(rx_uart1_data == 0x62)
			{
				m6n_rx_buf[cnt] = rx_uart1_data;
				cnt++;
			}
			else
				cnt = 0;
			break;
		case 27:
			m6n_rx_buf[cnt] = rx_uart1_data;
			cnt = 0;
			m6n_rx_cplt_flag = true;
			break;
		default:
			m6n_rx_buf[cnt] = rx_uart1_data;
			cnt++;
			break;
		}
		HAL_UART_Receive_IT(&huart1, &rx_uart1_data, 1);
	}
}

void HAL_TIM_PeriodElapsedCallback(TIM_HandleTypeDef *htim)
{
	if(htim->Instance == TIM2)
	{
		TIM2_flag = true;
		HAL_GPIO_TogglePin(LD_Debug_GPIO_Port, LD_Debug_Pin);
	}
}


/* USER CODE END 4 */
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


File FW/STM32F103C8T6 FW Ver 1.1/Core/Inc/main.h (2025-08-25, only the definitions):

#define D4_Pin GPIO_PIN_13
#define D4_GPIO_Port GPIOC
#define EN_Pin GPIO_PIN_14
#define EN_GPIO_Port GPIOC
#define RS_Pin GPIO_PIN_15
#define RS_GPIO_Port GPIOC
#define LD_HIGH_Pin GPIO_PIN_0
#define LD_HIGH_GPIO_Port GPIOA
#define LD_LOW_Pin GPIO_PIN_1
#define LD_LOW_GPIO_Port GPIOA
#define LD_MIN_Pin GPIO_PIN_2
#define LD_MIN_GPIO_Port GPIOA
#define SW_4_Pin GPIO_PIN_3
#define SW_4_GPIO_Port GPIOA
#define ADC_VIN_Pin GPIO_PIN_4
#define ADC_VIN_GPIO_Port GPIOA
#define LD_MAX_Pin GPIO_PIN_0
#define LD_MAX_GPIO_Port GPIOB
#define SPI1_CS_Pin GPIO_PIN_1
#define SPI1_CS_GPIO_Port GPIOB
#define SPI1_CE_Pin GPIO_PIN_2
#define SPI1_CE_GPIO_Port GPIOB
#define ATmega328p_Tx_Pin GPIO_PIN_10
#define ATmega328p_Tx_GPIO_Port GPIOB
#define ATmega328p_Rx_Pin GPIO_PIN_11
#define ATmega328p_Rx_GPIO_Port GPIOB
#define SW_1_Pin GPIO_PIN_12
#define SW_1_GPIO_Port GPIOB
#define SW_2_Pin GPIO_PIN_13
#define SW_2_GPIO_Port GPIOB
#define SW_3_Pin GPIO_PIN_14
#define SW_3_GPIO_Port GPIOB
#define ATmega328p_Reset_Pin GPIO_PIN_15
#define ATmega328p_Reset_GPIO_Port GPIOB
#define LD_Debug_Pin GPIO_PIN_8
#define LD_Debug_GPIO_Port GPIOA
#define GPS_Tx_Pin GPIO_PIN_9
#define GPS_Tx_GPIO_Port GPIOA
#define GPS_Rx_Pin GPIO_PIN_10
#define GPS_Rx_GPIO_Port GPIOA
#define Status_Pin GPIO_PIN_15
#define Status_GPIO_Port GPIOA
#define USB_EN_Pin GPIO_PIN_3
#define USB_EN_GPIO_Port GPIOB
#define D7_Pin GPIO_PIN_4
#define D7_GPIO_Port GPIOB
#define ISP_Pin GPIO_PIN_5
#define ISP_GPIO_Port GPIOB
#define D6_Pin GPIO_PIN_8
#define D6_GPIO_Port GPIOB
#define D5_Pin GPIO_PIN_9
#define D5_GPIO_Port GPIOB

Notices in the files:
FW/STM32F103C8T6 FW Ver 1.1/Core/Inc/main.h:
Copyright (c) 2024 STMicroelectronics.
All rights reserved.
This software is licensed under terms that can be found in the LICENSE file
